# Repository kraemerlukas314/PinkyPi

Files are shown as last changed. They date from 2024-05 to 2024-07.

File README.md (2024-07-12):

# PinkyPi
Ortho Staggered ergo split keyboard using Raspberry Pi Pico \
\
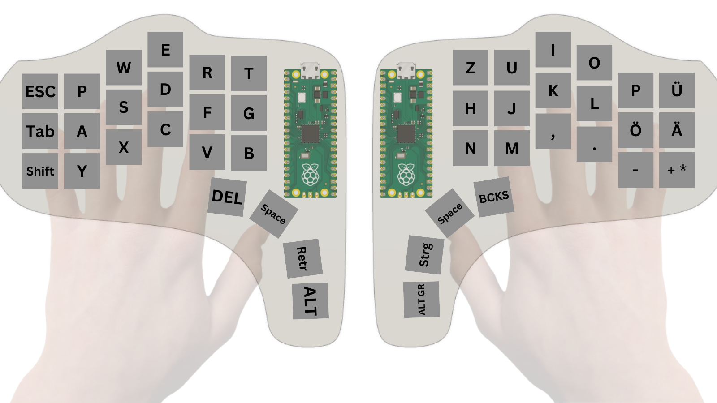
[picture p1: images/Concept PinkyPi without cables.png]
PinkyPi Concept
 \
\
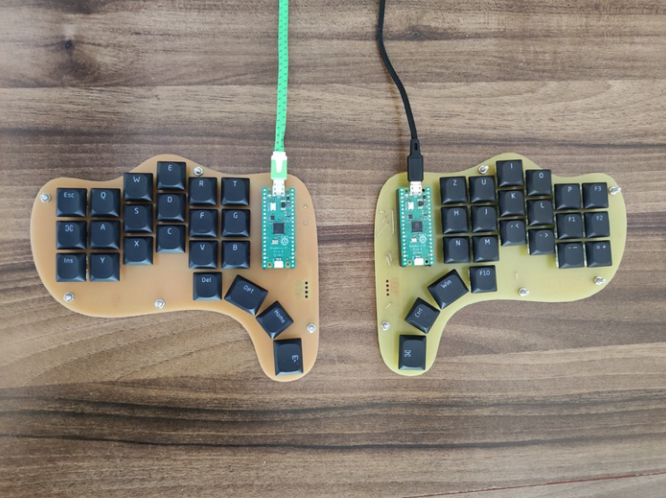
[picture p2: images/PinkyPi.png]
PinkyPi Keyboard


# Flash CircuitPython firmware:
0. Connect Pico to PC while holding down the "Bootsel" button
1. Open Thonny
2. Go to: Tools -> Options -> Interpreter
3. Choose CircuitPython (RP2040)
4. Click on "Install or update CircuitPython"
5. Rest is self-explanatory, firmware version 9.0.5 is recommended (code is only tested on this version)

# Run the keyboard code:
1. Flash CircuitPython firmware
2. copy "lib" folder of this repo to the Picos internal storage
3. Open Thonny
4. Execute the actual .py code file
5. (rename file to main if it should run automatically on Pico startup)

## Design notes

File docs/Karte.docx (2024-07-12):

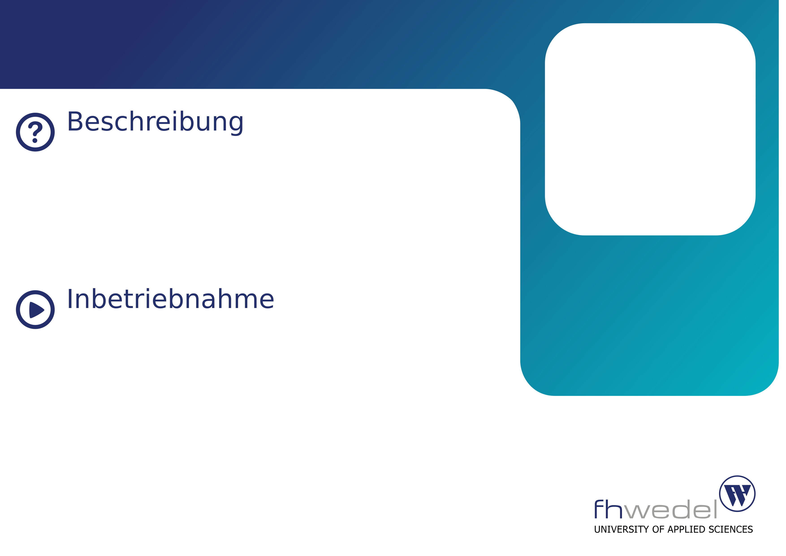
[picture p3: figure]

Ergonomische Tastatur

In diesem Semester wurde eine ergonomische Tastatur aus zwei Hälften gebaut, sodass man die Breite der beiden Hälften frei anpassen kann.

Außerdem sind die Tastenreihen ungewöhnlich verschoben, um die unterschiedliche Länge der Finger zu kompensieren.

Wer hat’s gemacht

Lukas Krämer

SoSe 2024

Die beiden Hälften müssen jeweils per Micro USB Kabel mit dem Computer verbunden werden.

Anschließend sollte die Tastatur wie gewohnt funktionieren, lediglich die Buchstaben auf den Tastenkappen stimmen an manchen Stellen nicht mit der tatsächlichen Taste überein.

Sonderzeichen und Zahlen sind größtenteils nicht möglich.

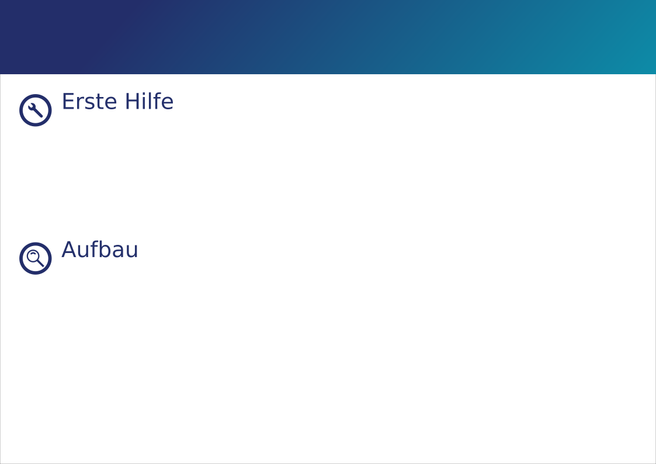
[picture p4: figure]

Ergonomische Tastatur

Prüfe zunächst, ob beide Hälften noch einen Mikrocontroller aufgesteckt haben (grüne Platine in der Größe von ca. drei Tastenkappen).

Falls die LEDs neben den Micro USB Ports beim Einstecken der beiden Hälften zwar blinken, aber sie trotzdem nicht funktionieren, besitzt dein USB Kabel vermutlich keine Datenleitungen oder ist beschädigt.

Ansonsten kann es sein, dass die Mikrocontroller nicht mehr den richtigen Code enthalten.

Die beiden Hälften bestehen aus jeweils 22 Tasten und einem Raspberry Pi Pico, der ausließt, ob eine Taste gedrückt wurde und dann gegebenfalls die entsprechende Taste an den Computer sendet. Mehr Informationen können dem GitHub Repository entnommen werden:

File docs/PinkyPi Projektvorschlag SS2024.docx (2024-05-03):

Projekt-Vorschlag

Projekt: PinkyPi

Dokument: Projekt-Vorschlag PinkyPi SS2024

Version: 1.0.0

Datum: 15.04.2024

Status: vorläufig final

Zusammenfassung

Unsere heutigen Tastaturen existieren mittlerweile seit knapp 150 Jahren in nahezu unveränderter Form und das trotz der sich stetig weiterentwickelnden Arbeitsweisen und Bedürfnissen. Ein ergonomisches Split-Keyboard bietet die Möglichkeit, diesen Fortschritt anzuerkennen und den Bedürfnissen moderner Nutzer gerecht zu werden. Durch die Aufteilung der Tastatur in zwei Hälften kann die Handhaltung optimiert und damit eine natürlichere Armposition ermöglicht werden, um Erkrankungen wie RSI (Repetitive strain injury) effektiv vorzubeugen.

1 Ziel

Das Hauptziel des Projektes besteht zunächst darin, einen funktionsfähigen Prototypen eines ergonomischen Split-Keyboards zu bauen, der eine Verbesserung zum Status Quo bezüglich Ergonomie darstellen sollte.
Darüber hinaus verspreche ich persönlich mir vom Projekt das Erlernen der PCB Design Software KiCad, um auch in Zukunft eigene Platinen für Projekte entwerfen zu können.

2 Ist-Situation

Wie bereits erwähnt, stammen unsere heutigen Tastaturen aus der Zeit der Schreibmaschinen, bei denen die Platzierung der Buchstaben so gewählt wurde, dass sich die Typenhebel nicht ineinander verfangen. Auch wenn diese Limitierung heutzutage keine Rolle mehr spielt, ist die traditionelle Tastenanordnung noch weit verbreitet.
Da das Erlernen eines neuen Layouts jedoch viel Übung erfordert, werde ich mich in diesem Projekt lediglich auf die Entwicklung einer verbesserten Ergonomie konzentrieren, bei Bedarf lässt sich das Layout zudem jederzeit per Software verändern. Das größte Problem an herkömmlichen Tastaturen ist dabei das starke Abknicken der Handgelenke, wie die folgende Grafik veranschaulicht:

(https://trulyergonomic.com/ergonomic-keyboards/wp-content/uploads/Truly-Ergonomic-Cleave-Reduce-Conventional-Keyboard-Pain-27-768x403.gif)

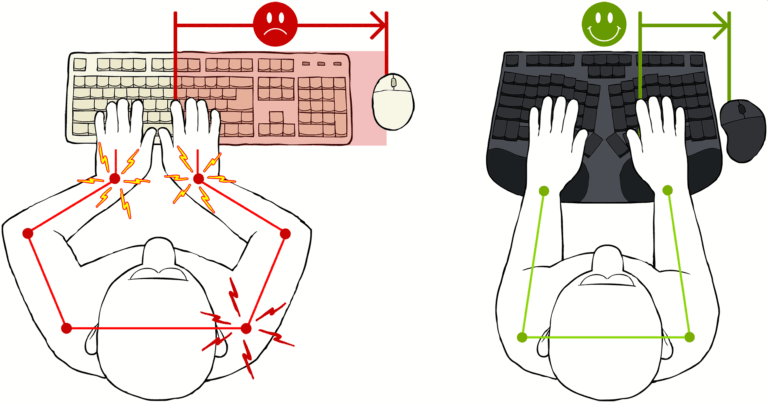
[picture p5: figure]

3 Projekt-Ansatz

Das PinkyPi Keyboard besteht aus zwei Hälften, die jeweils aus 22 Tasten und einem Raspberry Pi Pico bestehen. Die beiden Hälften sind untereinander verbunden, wobei eine der beiden Hälften zusätzlich mit dem PC verbunden wird.

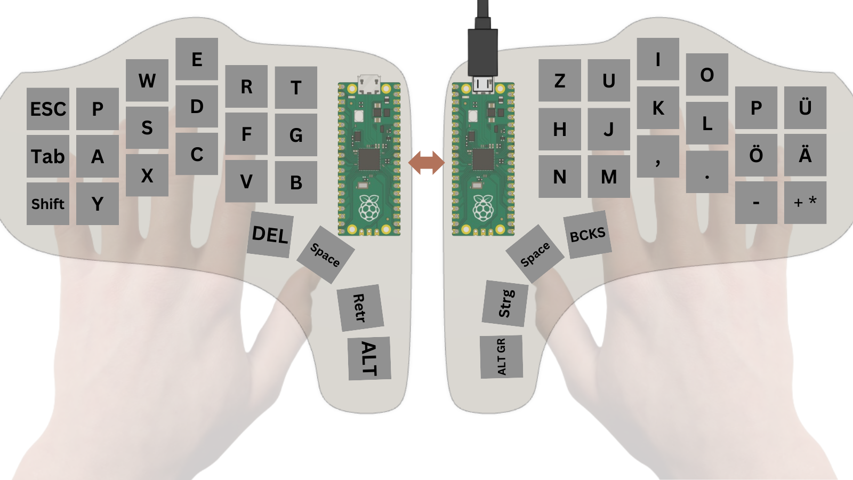
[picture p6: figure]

4 Deliverables

Wie auch schon im letzten Semester, wird zum PinkyPi Projekt ebenfalls eine Entwickler- sowie Benutzerdoku geschrieben, damit das Projekt genutzt und gewartet werden kann. Zusätzlich ist geplant, den Source Code und die Design-Dateien öffentlich auf GitHub zur Verfügung zu stellen, damit theoretisch auch andere an meinem Projekt weiterarbeiten können bzw. ich selbst jederzeit auf die Dateien zurückgreifen kann.
Idealerweise sollte die fertige Tastatur in den Räumlichkeiten der FH zur Show ausliegen, damit sie von anderen Studierenden und Besuchern (zum Beispiel am Tag der offenen Tür) ausprobiert werden kann.

5 Material

Die für das Projekt benötigte Hardware ist in der folgenden Tabelle aufgelistet:

Stückliste

Posten | Bezeichnung | Einzelpreis | Menge | Gesamtpreis | Bezugsquelle
1. | RasPi Pico | - | 2 | 10,99€ | Amazon
2. | Gateron Ks-33 Low-Profile-Tastenschalter | - | 44 (65er Packung) | 35,99€ | Amazon
3. | Keycaps | - | 44 (volles Set enthält mehr Tasten) | 27,99€ | Amazon
4. | Micro-USB Kabel | | | vorhanden
5. | Dünnes Kabel | | 1 Meter | vorhanden
6. | M3 14-20mm Schrauben | | | vorhanden

6 Kosten

Wie der obigen Stückliste zu entnehmen ist, belaufen sich die initialen Kosten auf 75€, wobei zusätzlich noch ein Micro-USB Kabel, etwas Kabel zum Löten sowie gängiges Werkzeug wie Lötkolben, Lötzinn und ein M3 Schraubendreher benötigt werden.
Laufende Kosten fallen nahezu keine an, selbst im Fall eines Defektes sind beispielsweise noch genügend Ersatz-Tasten und Keycaps vorhanden, lediglich von den beiden Raspberry Pi Picos ist kein Ersatz vorhanden.

7 Zeitliche Planung

Kalenderwoche | Phase | Todo
15 | Brainstorming | - Auf Idee festlegen
16 | Bestellung | - Benötigte Hardware auflisten - Projektplanung a) Projektvorschlag Dokument b) Zeitplan erstellen c) Erstes Mockup für Layout - Hardware bestellen
17 | Vorbereitung, PCB Design (rechts) | - Git + GitHub Repo erstellen - KiCad einrichten und benötigte Komponenten kreieren a) Pi Pico b) Gateron Schalter - Schematic erstellen - kleines Test-PCB entwerfen und Form davon 3D drucken (um Maße für Schalter zu prüfen)
18 | | - PCB Outline entwerfen - PCB Design fertigstellen
19 | PCB Bestückung, Test | - PCB fertigen und bestücken - Funktionstest: a) jeden Schalter auslesen b) Tastatur emulieren mit Pi Pico
20 | PCB Design (links) | - Schematic (links) - PCB Design (links) - Fertigung des PCBs
21 | | - Bestückung links - Testen der linken Seite: a) jeden Schalter auslesen - Verlöten des Kommunikationskabels zwischen Picos
22 | Kommunikation der beiden Hälften | - Kommunikation zwischen Pico und Pico festlegen (PCB könnte alle): a) SPI b) I2C c) UART d) Custom - sinnvolles Format für Kommunikation überlegen, um Buchstabe vom einen Pico zum anderen zu schicken (evtl. die anderen um Rat fragen)
23 | | - Code für jeweilige Seite entwickeln, der Tastendruck in Buchstabe umwandelt (bzgl. genereller Architektur um Rat fragen)
24 | | - Buchstabe der linken Seite nach rechts schicken - rechts kann mit empfangenen Buchstaben umgehen - Emulation des Tastendrucks an PC
25 | Gehäuse | - Design eines Gehäuses - Bei genug Zeit: Handballenauflage
26 | | - Puffer (Shortcuts implementieren) - Entwicklerdoku
27 | | Puffer (Präsentation erstellen) - Benutzerdoku - Veröffentlichung auf GitHub
28 | Abschluss | - Vorstellung und Demonstration

8 Risiken

Das vermutlich größte Risiko am Projekt ist der Faktor Zeit, da ich mir nicht nur vorgenommen habe, ein neues Programm (KiCad) zu erlernen, sondern dies auch meine erste selbstgebaute Tastatur ist, was die Zeiteinschätzung im Vorfeld zusätzlich erschwert. Insbesondere der benötigte Software-Aufwand ist nur schwer einschätzbar, weshalb ich notfalls noch zwei Pufferwochen in den Zeitplan eingebaut habe (ließe sich im Extremfall weiter ausweiten, zum Beispiel durch Auslassen des Gehäuses und von Shortcuts).
Natürlich hoffe ich trotzdem, das Projekt fristgerecht und vollständig fertigstellen zu können, damit es anschließend auch tatsächlich genutzt werden kann.

SS2024 Name des Projekts: PinkyPi 2024-04-15

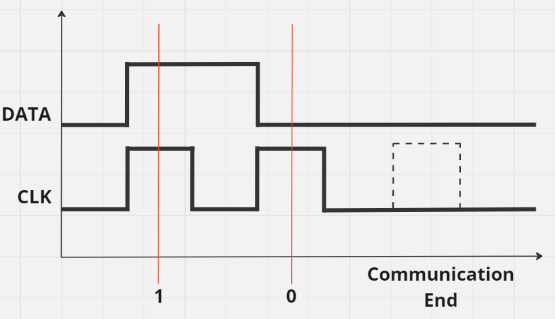
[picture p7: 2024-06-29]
images/Communication Protocol.png

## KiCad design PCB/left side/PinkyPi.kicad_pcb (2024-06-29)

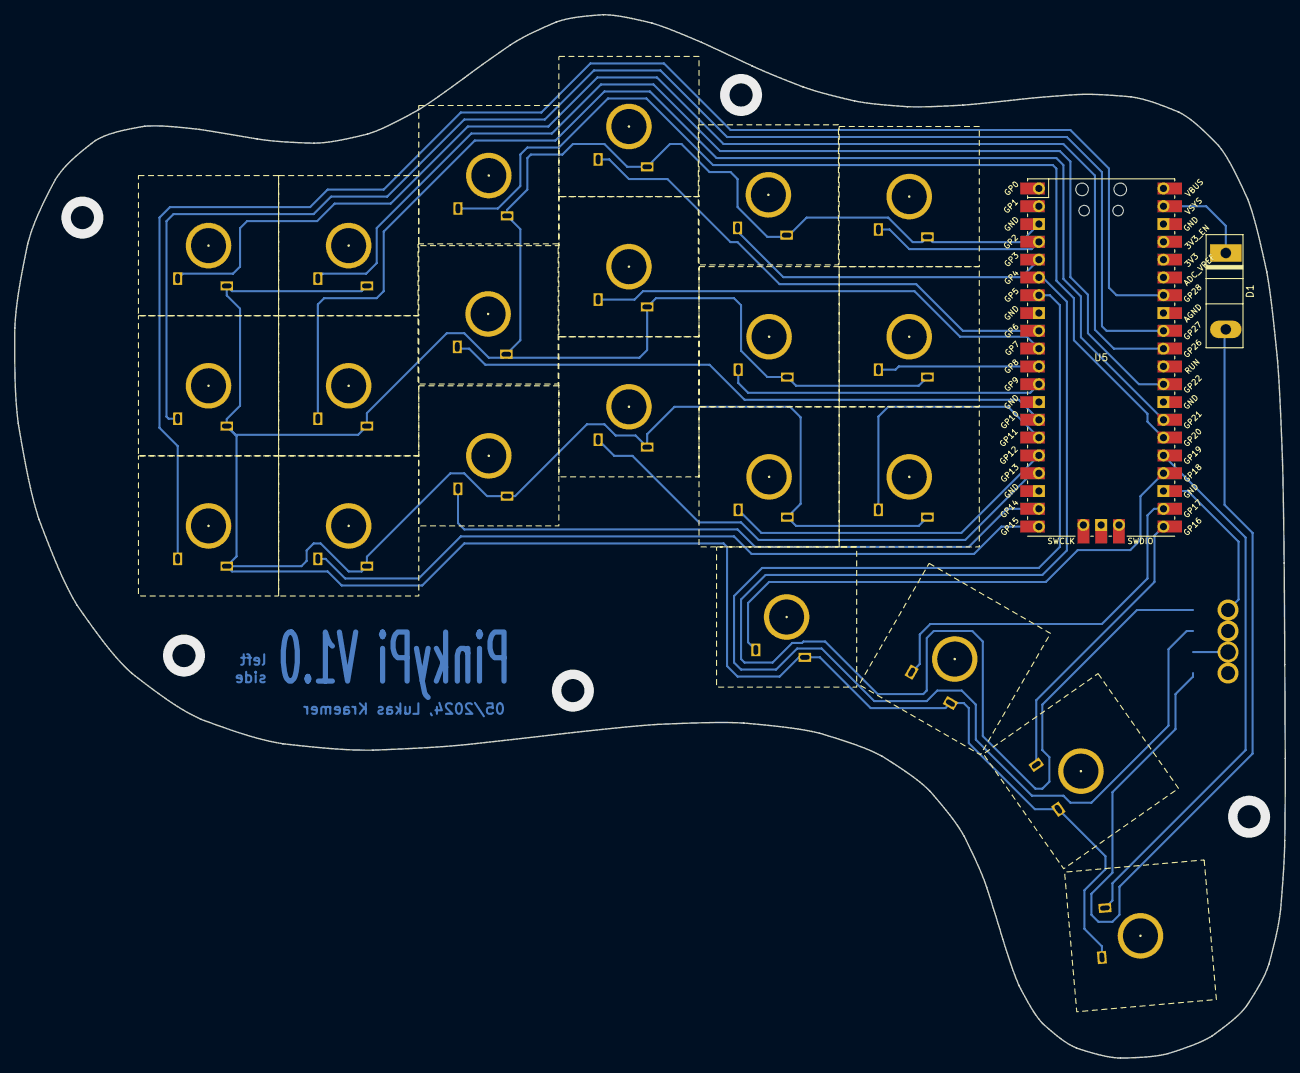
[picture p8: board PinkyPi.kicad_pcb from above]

Board: 2 copper layers, 181.3 x 148.9 mm, 25 parts (0 on the bottom side), 27 nets.

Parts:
D1: STBR3008WY; D_DO-247_Vertical
U1, U2, U3, U4, U6, U7, U8, U9, U10, U11, U12, U13, U14, U15, U16, U17, U18, U19, U20, U21, U22, U24: Gateron Switch Footprint
U5: Pico; RPi_Pico_SMD_TH
U23: Communication Port

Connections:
/L1: U1.2 (OUT), U5.4 (GPIO2)
/L2: U5.5 (GPIO3), U7.2 (OUT)
/L3: U5.9 (GPIO6), U12.2 (OUT)
/L4: U2.2 (OUT), U5.10 (GPIO7)
/L5: U5.11 (GPIO8), U8.2 (OUT)
/L6: U5.12 (GPIO9), U13.2 (OUT)
/L7: U5.32 (GPIO27_ADC1), U18.2 (OUT)
/L8: U5.14 (GPIO10), U9.2 (OUT)
/L9: U5.15 (GPIO11), U14.2 (OUT)
/L10: U4.2 (OUT), U5.16 (GPIO12)
/L11: U5.17 (GPIO13), U10.2 (OUT)
/L12: U5.34 (GPIO28_ADC2), U20.2 (OUT)
/L13: U5.19 (GPIO14), U6.2 (OUT)
/L14: U5.20 (GPIO15), U11.2 (OUT)
/L15: U5.21 (GPIO16), U17.2 (OUT)
/L16: U5.24 (GPIO18), U16.2 (OUT)
/L17: U5.25 (GPIO19), U19.2 (OUT)
/L18: U5.26 (GPIO20), U15.2 (OUT)
/L19: U3.2 (OUT), U5.27 (GPIO21)
/L20: U5.29 (GPIO22), U22.2 (OUT)
/L21: U5.31 (GPIO26_ADC0), U21.2 (OUT)
/L22: U5.22 (GPIO17), U24.2 (OUT)
GND: U1.1 (IN), U2.1 (IN), U3.1 (IN), U4.1 (IN), U5.3 (GND), U5.8 (GND), U5.13 (GND), U5.18 (GND), U5.23 (GND), U5.28 (GND), U5.38 (GND), U6.1 (IN), U7.1 (IN), U8.1 (IN), U9.1 (IN), U10.1 (IN), U11.1 (IN), U12.1 (IN), U13.1 (IN), U14.1 (IN), U15.1 (IN), U16.1 (IN), U17.1 (IN), U18.1 (IN), U19.1 (IN), U20.1 (IN), U21.1 (IN), U22.1 (IN), U23.2 (GND), U24.1 (IN)
unnamed: D1.2 (A), U23.1 (VCC)
unnamed: D1.1 (K), U5.39 (VSYS)
unnamed: U5.7 (GPIO5), U23.3 (RX)
unnamed: U5.6 (GPIO4), U23.4 (TX)

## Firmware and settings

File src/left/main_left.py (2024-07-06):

import board
import digitalio
import time
import usb_hid
from adafruit_hid.keyboard import Keyboard
from adafruit_hid.keycode import Keycode

kbd = Keyboard(usb_hid.devices)

key_map_left = {
    "26": (Keycode.ESCAPE, False, 0),
    "27": (Keycode.TAB, False, 0), # tab
    "28": (100, False, 0),
    "22": (Keycode.Q, False, 0),
    "21": (Keycode.A, False, 0),
    "15": (Keycode.Y, False, 0),
    "20": (Keycode.W, False, 0),
    "10": (Keycode.S, False, 0),
    "14": (Keycode.X, False, 0),
    "6": (Keycode.E, False, 0),
    "7": (Keycode.D, False, 0),
    "13": (Keycode.C, False, 0),
    "3": (Keycode.R, False, 0),
    "9": (Keycode.F, False, 0),
    "12": (Keycode.V, False, 0),
    "2": (Keycode.T, False, 0),
    "8": (Keycode.G, False, 0),
    "11": (Keycode.B, False, 0),
    "18": (42, False, 0),
    "17": (44, False, 0),
    "16": (225, False, 0),
    "19": (227, False, 0)
}

# Initialize all pins as input with pull-up resistors
for pin_string in key_map_left.keys():
    pin_number = "GP" + pin_string
    pin = getattr(board, pin_number)
    pin = digitalio.DigitalInOut(pin)
    pin.direction = digitalio.Direction.INPUT
    pin.pull = digitalio.Pull.UP
    keycode, pressed, timestamp = key_map_left[pin_string]
    key_map_left[pin_string] = (pin, keycode, pressed, timestamp)

while True:
    current_time = time.monotonic_ns()  # Get the current time in nanoseconds
    
    for pin_string, (pin, keycode, pressed, timestamp) in key_map_left.items():
        if not pin.value:  # Key is pressed (pin is low)
            if not pressed:  # key was not previously pressed
                kbd.press(keycode)
                key_map_left[pin_string] = (pin, keycode, True, current_time)
            else:  # Key is already pressed
                if current_time - timestamp > 50 * 1_000_000:  # 50ms in nanoseconds
                    kbd.press(keycode)  # Continuously send key press
                    key_map_left[pin_string] = (pin, keycode, True, current_time)  # Update timestamp to current time
        else:  # Key is released
            if pressed:  # Key was previously pressed
                kbd.release(keycode)
                key_map_left[pin_string] = (pin, keycode, False, 0)

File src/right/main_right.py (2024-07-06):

import board
import digitalio
import time
import usb_hid
from adafruit_hid.keyboard import Keyboard
from adafruit_hid.keycode import Keycode

kbd = Keyboard(usb_hid.devices)

# for more information about key mapping refer to:
# https://usb.org/sites/default/files/hut1_21_0.pdf#page=83
key_map_right = {
    # PIN: (Keycode to press, already Pressed?, timestamp when it was pressed in ns)
    "28": (Keycode.Z, False, 0),
    "21": (Keycode.H, False, 0),
    "17": (Keycode.N, False, 0),
    "27": (Keycode.U, False, 0),
    "19": (Keycode.J, False, 0),
    "16": (Keycode.M, False, 0),
    "26": (Keycode.I, False, 0),
    "20": (Keycode.K, False, 0),
    "18": (54, False, 0),das ist 
    "22": (Keycode.O, False, 0),
    "7": (Keycode.L, False, 0),
    "6": (55, False, 0),
    "3": (Keycode.P, False, 0),
    "9": (Keycode.O, False, 0),  # Ö
    "15": (Keycode.MINUS, False, 0),
    "2": (Keycode.U, False, 0),  # Ü
    "8": (Keycode.A, False, 0),  # Ä
    "10": (57, False, 0),
    "11": (76, False, 0),
    "13": (Keycode.CONTROL, False, 0),
    "14": (Keycode.ALT, False, 0),
    "12": (Keycode.RETURN, False, 0)
}

# Initialize all pins as input with pull-up resistors
for pin_string in key_map_right.keys():
    pin_number = "GP" + pin_string
    pin = getattr(board, pin_number)
    pin = digitalio.DigitalInOut(pin)
    pin.direction = digitalio.Direction.INPUT
    pin.pull = digitalio.Pull.UP
    keycode, pressed, timestamp = key_map_right[pin_string]
    key_map_right[pin_string] = (pin, keycode, pressed, timestamp)

while True:
    current_time = time.monotonic_ns()  # Get the current time in nanoseconds
    
    for pin_string, (pin, keycode, pressed, timestamp) in key_map_right.items():
        if not pin.value:  # Key is pressed (pin is low)
            if not pressed:  # key was not previously pressed
                kbd.press(keycode)
                key_map_right[pin_string] = (pin, keycode, True, current_time)
            else:  # Key is already pressed
                if current_time - timestamp > 50 * 1_000_000:  # 50ms in nanoseconds
                    kbd.press(keycode)  # Continuously send key press
                    key_map_right[pin_string] = (pin, keycode, True, current_time)  # Update timestamp to current time
        else:  # Key is released
            if pressed:  # Key was previously pressed
                kbd.release(keycode)
                key_map_right[pin_string] = (pin, keycode, False, 0)

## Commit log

2024-05-03 inital commit
    [PinkyPi-B_Cu.gbr, PinkyPi-B_Mask.gbr, PinkyPi-B_Paste.gbr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]
2024-05-04 added PCB left
    [PinkyPi.kicad_pcb, PinkyPi.kicad_sch]
2024-06-29 own communication protocol working
    [PinkyPi-B_Cu.gbr, PinkyPi-B_Mask.gbr, PinkyPi-B_Paste.gbr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]
2024-07-06 working using two USB cables
